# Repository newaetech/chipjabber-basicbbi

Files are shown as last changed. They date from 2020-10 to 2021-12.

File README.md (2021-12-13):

# ChipJabber-BasicBBI

What the heck is Body Biasing Injection? This is a method of injecting faults into the backside of an IC, which results in an injection somewhere between EMFI & Laser-FI. This work has been presented since 2012, yet there has been less follow on work compared to topics such as EMFI & Laser FI. ChipJabber-BasicBBI tries to help with that by making available both the injection tool & target for all!

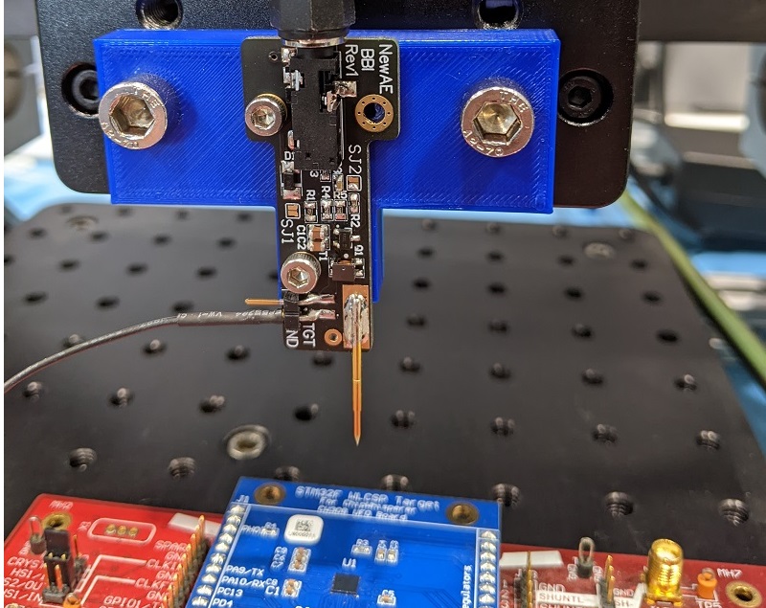
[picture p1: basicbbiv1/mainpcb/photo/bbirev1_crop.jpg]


You can see the following papers for the origins of this:

* Philippe Maurine. **Techniques for EM Fault Injection: Equipments and Experimental Results**. FDTC 2012: Workshop on Fault Diagnosis and Tolerance in Cryptography. 9 Sept. 2012. [PDF Available](https://hal-lirmm.ccsd.cnrs.fr/lirmm-00761778/document).

* Philippe Maurine, Karim Tobich, Thomas Ordas, Pierre Yvan Liardet. **Yet Another Fault Injection Technique: by Forward Body Biasing Injection**. YACC’2012: Yet Another Conference on Cryptography, Sep 2012, Porquerolles Island, France.  [PDF Available](https://hal-lirmm.ccsd.cnrs.fr/lirmm-00762035/document).

* Karim Tobich, Philippe Maurine, Pierre Yvan Liardet, Mathieu Lisart, Thomas Ordas. **Voltage Spikes on the Substrate to Obtain Timing Faults**. 2013 Euromicro Conference on Digital System Design, Los Alamitos, CA, 2013, pp. 483-486. [PDF Available](https://www.researchgate.net/profile/Philippe_Maurine/publication/262352179_Voltage_Spikes_on_the_Substrate_to_Obtain_Timing_Faults/links/54b805100cf2c27adc487b12/Vo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)

* Noemie Beringuier-Boher, Marc Lacruche, David El-Baze, Jean-Max Dutertre, Jean-Baptiste Rigaud, Philippe Maurine. **Body Biasing Injection Attacks in Practice**. In Proceedings of the Third Workshop on Cryptography and Security in Computing Systems (CS2 '16), 2016. [PDF Available](https://dl.acm.org/doi/pdf/10.1145/2858930.2858940)

## BBI Made Simple

BBI uses a simple idea - use a physical probe on the IC die *backside*. While it turns out that WLCSP devices expose the backside (or have some flimsy film over it you can remove easily), allowing you to perform BBI without becoming [John McMaster](https://twitter.com/johndmcmaster).

The idea of this repo is to perform BBI using a simple probe, which uses a transformer to generate the required pulses. This looks something like this:

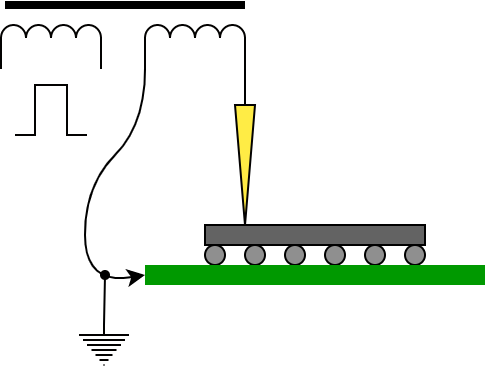
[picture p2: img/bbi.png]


## CARDIS 2020 Paper

This work was presented at CARDIS 2020, see an extended version of the paper in the [CARDIS](cardis2020/ChipJabber_BBI.pdf) directory of this repository. If you use these results (or this design), please reference:

```
O'Flynn, Colin. (2021) Low-Cost Body Biasing Injection (BBI) Attacks on WLCSP Devices.
In: Liardet PY., Mentens N. (eds) Smart Card Research and Advanced Applications. CARDIS 2020.
Lecture Notes in Computer Science, vol 12609. Springer, Cham. https://doi.org/10.1007/978-3-030-68487-7_11
```

You can pull the citation from the [SpringerLink page](https://link.springer.com/chapter/10.1007/978-3-030-68487-7_11#citeas) as well.

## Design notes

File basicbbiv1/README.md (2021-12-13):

# BasicBBI-Rev1

The BasicBBI Rev1 allows assembly with off-the-shelf parts, while adding some critical features such as mounting holes and protection from easily destroying the probe. The current test board ('PCB Rev A') looks like this:

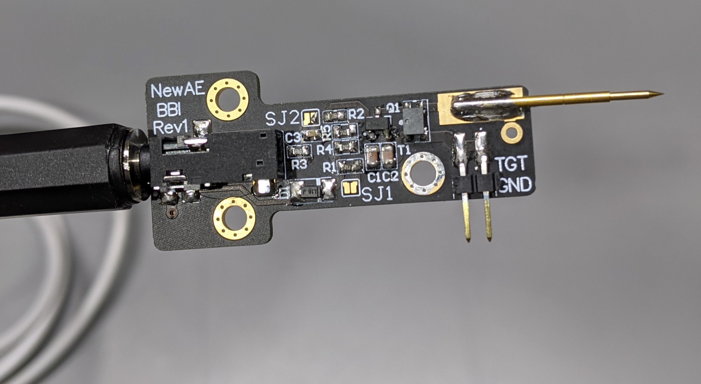
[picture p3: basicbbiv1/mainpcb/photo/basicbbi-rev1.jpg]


It requires a 3.3V logic-level waveform from the ChipWhisperer board (or any other signal source).

## Usage

See the CARDIS 2020 paper for general information on the design & usage of this device. You'll need a 3.5mm, 4-conductor "tip ring ring sleeve" cable. You can use any generic off-the-shelf cable, or for example you can even buy from Digi-Key cables such as 839-1600-ND which saves you needing to cut a cable in half!

```
 +------------ Pulse input (logic level drive, AC-coupled)
 |  +--------- Optional pull-up or termination.
 |  |
<[] [] [] []|======
       |  |
       |  +--- GND
       +------ Voltage In (range, 0 to 30V. Use small current limit such as 50mA)
```

To prevent you from blowing up the transformer T1 or MOSFET Q1, the input pulse drive is AC-coupled. You can remove this coupling by shorting `J2`.

The "optional pull-up" was originally designed to allow driving the BBI probe directly from a ChipWhisperer "glitch" output - this doesn't work well in practice, as you need a very long "glitch width" in order to get a positive
spike on the MOSFET gate (and not the negative spike you'll see with narrow pulses). Mostly you can leave the "optional pull up" wire disconnected without issue.

### Connections

1. Connect a pulse generator to the `Pulse Input`. In the COSADE BBI work, the ChipWhisperer-Lite is used. You can use either the HS2 output, or if you need to use HS2 for clock output, the header JP8 has the signals 
   routed to the "glitch_lp" and "glitch_hp" MOSFETs. The center pin has the "glitch_lp" mosfet drive signal, and can be routed to the `Pulse input` of the BBI probe.

2. Connect a 0V to 30V power source that has a 100~mA current limit to the probe. A 75-ohm resistor tries to limit current, but at 30V this means up to 400mA will flow, so it is preferred if you have a current limited supply.

3. Place the bbi probe over your WLCSP device. If you aren't sure if the package exposes the die backside, use a DMM to check for a 20K-400K resistance between the die backside and VCC or GND.

4. Connect the output of the transformer "ground" pin (the not-needle-side) to target pcb gnd.

5. Hit that fault inject button!

If you want a starting point, see the Jupyter notebook for the CARDIS paper.

## Parts

The following are the 'specific' parts used in the design (format is `QTY, PART NUMBER, DESIGNATOR`).

```
1,B260A,D1
1,AO3422,Q1
1,ATB322524,T1
1,TSM-102-01-L-SH,J1
1,P25-0123,PROBE
```

If you need to sub `D1` or `Q1`:

* D1 is for reverse polarity protection so can be skipped. If you can't find that part use the following:
	* DO-214AC (SMA) package (SOD123 packages fit - a SOD123 package diode is in the photo)
	* Schottky
	* 500mA or higher current rating
	* 40V or higher voltage rating
* Q1 is a logic-level MOSFET in SOT23 package. If you need a replacement use the following criteria:
	* N-Channel
	* Check pinout matches expected
	* Logic level drive (spec of something like 2.5V 'Max Rds On', 4.5V 'Min Rds On')
	* 1.8A or higher (only for pulse current reasons - can get away with smaller one)
	* 45V or higher Drain to Source Voltage (Vdss)

Currently (Dec 2021) there is limited stock of suitable MOSFETs, if you can't find one see Issue #1. 
 
`J1` can be sub'd with any header that you can solder, or even just wire.

`PROBE` is a sharp pogo pin. The Harwin `P25-0123` is a good low-cost option, you can get fancier (smaller point) probes too.

The other parts are very generic, I didn't have part numbers for them:

```
1, 100n 0603 [Generic]
2, 4.7uF 0805 50V or 63V [Generic]
1, 10K 0805 5% or 1% [Generic]
2, 1K 0603 5% or 1% [Generic]
```

## Schematic

A PDF of the schematic is in the repo, here is a image for convenience:

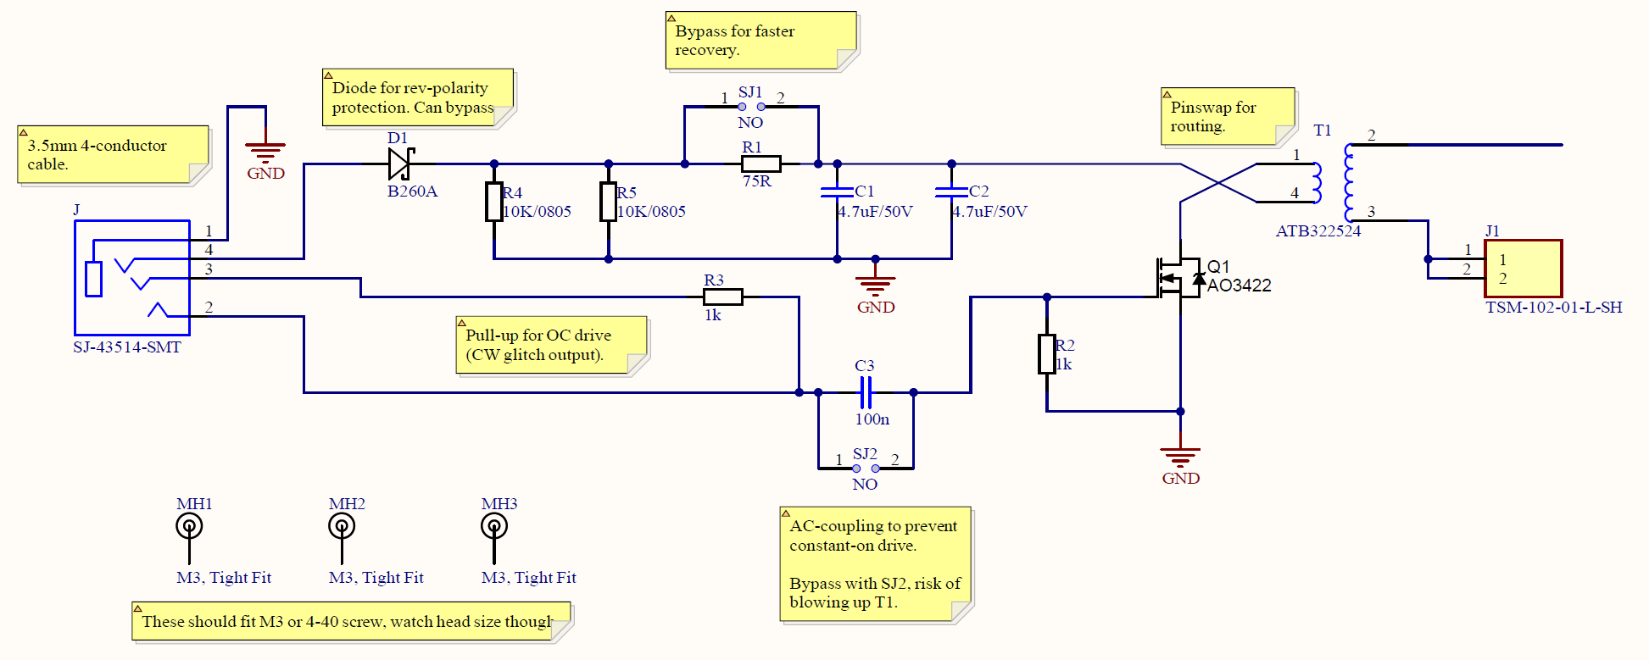
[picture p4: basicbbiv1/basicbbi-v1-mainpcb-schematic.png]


## PCB

PCB gerbers are in the repo.

One version of the gerbers has been generated with the Bantam Mill output standard. The vias around the mounting holes have also been removed in this version (since they would probably damage your bit and do nothing with a milled PCB).

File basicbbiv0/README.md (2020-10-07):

# ChipJabber-BasicBBI Rev0

This revision of the BBI probe matches the one in Colin's CARDIS 2020 paper. It was originally designed to be made on a Bantam PCB mill, so is extremely bare-bones.

## Construction Instructions

### PCB Details

The PCB was built with parts on hand, so it is very bare-bones. You might want to see Rev1 edition for a better design.

The following shows the schematic:

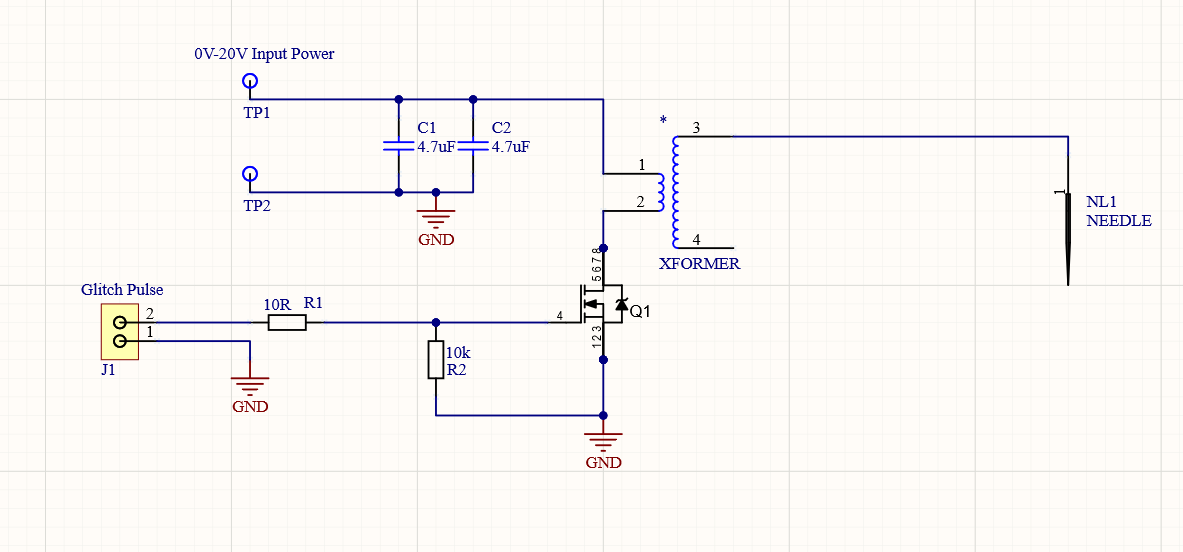
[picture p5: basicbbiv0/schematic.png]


And the base PCB:

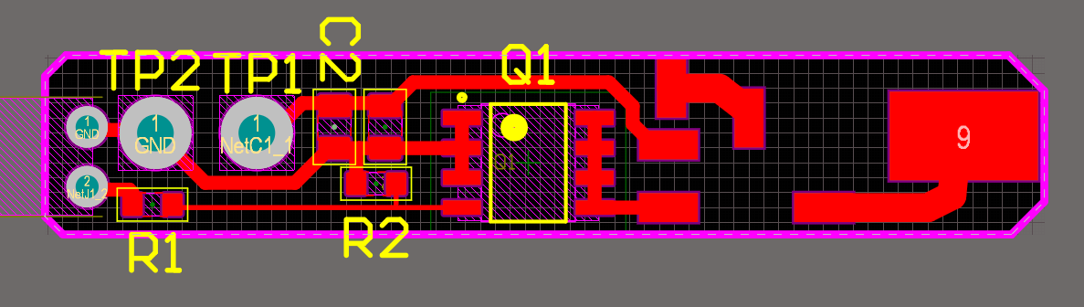
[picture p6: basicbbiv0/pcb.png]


Gerber files are in the relevant directory, they should be loadable in the Bantam PCB milling software. If you are going to the effort of ordering PCBs, suggest to use the V1 edition instead which more effort was put into.

### Custom Coil Winding

The "heart" of BasicBBI is a custom wound coil. This coil is surprisingly uncritical how you wind it, but you've got to do it. The suggested coil is based on these parts:

* Fair-Rite rod [3061990871](https://www.digikey.ca/en/products/detail/fair-rite-products-corp/3061990871/8599472)
* 26 AWG, and 30 AWG magnetic wire, available in [Sparkfun PRT-11363](https://www.digikey.ca/en/products/detail/sparkfun-electronics/PRT-11363/5230957)

Optionally, you may find some Super-Glue + Accelerator/Activator convenient to freeze your windings in place. 

To wind the coil:

1. Wind 6 turns of 26 AWG magnet wire, this is the primary.
2. Use some glue (the super-glue + accelerator is easiest here) to hold the winding in place.
3. Wind 60 turns of the 30 AWG magnet wire on-top. You'll have to go back and forth several times. It can be fairly messy and still seems to work fine.

Leave lots of spare wire, as you can tin the wires once you see how it fits onto the PCB. See details below.

### PCB Assembly

In addition to the coil, you will need a pogo pin. Harwin P25-0123 is available on Digikey & Mouser, otherwise you can find similar ones on various cheaper sites if you wish.

The assembled probe could look something like this:

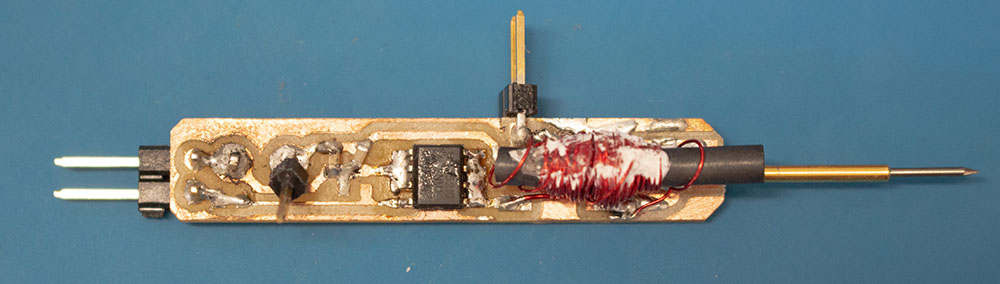
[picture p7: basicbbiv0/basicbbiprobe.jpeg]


## Usage Instructions

To use this probe:

1. Connect a pulse generator to the MOSFET gate. In the COSADE BBI work, the ChipWhisperer-Lite is used. The signal routed to the on-board mosfet is tapped off at JP8, the center pin as the "glitch_lp" mosfet drive signal.

2. Connect a power source that has a 100~mA current limit to the probe. If you don't have a current limited supply, use a ~100 ohm resistor inline. The probe discharges from the capacitors on-board anyway. **WARNING: Using a non-current-limited supply it becomes likely you accidentally turn on the MOSFET for too long, which will have a direct short across the supply rails.**

3. Place the bbi probe over your WLCSP device. If you aren't sure if the package exposes the die backside, use a DMM to check for a 20K-400K resistance between the die backside and VCC or GND.

4. Connect the output of the transformer "ground" pin (the not-needle-side) to target pcb gnd.

5. Hit that fault inject button!

If you want a starting point, see the Jupyter notebook for the CARDIS paper.

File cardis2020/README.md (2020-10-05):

# Jupyter Notebooks

This repo contains the notebooks used for data capture, along with generating figures used in Colin's
paper in CARDIS2020. You can see an example of the Jupyter notebook here:

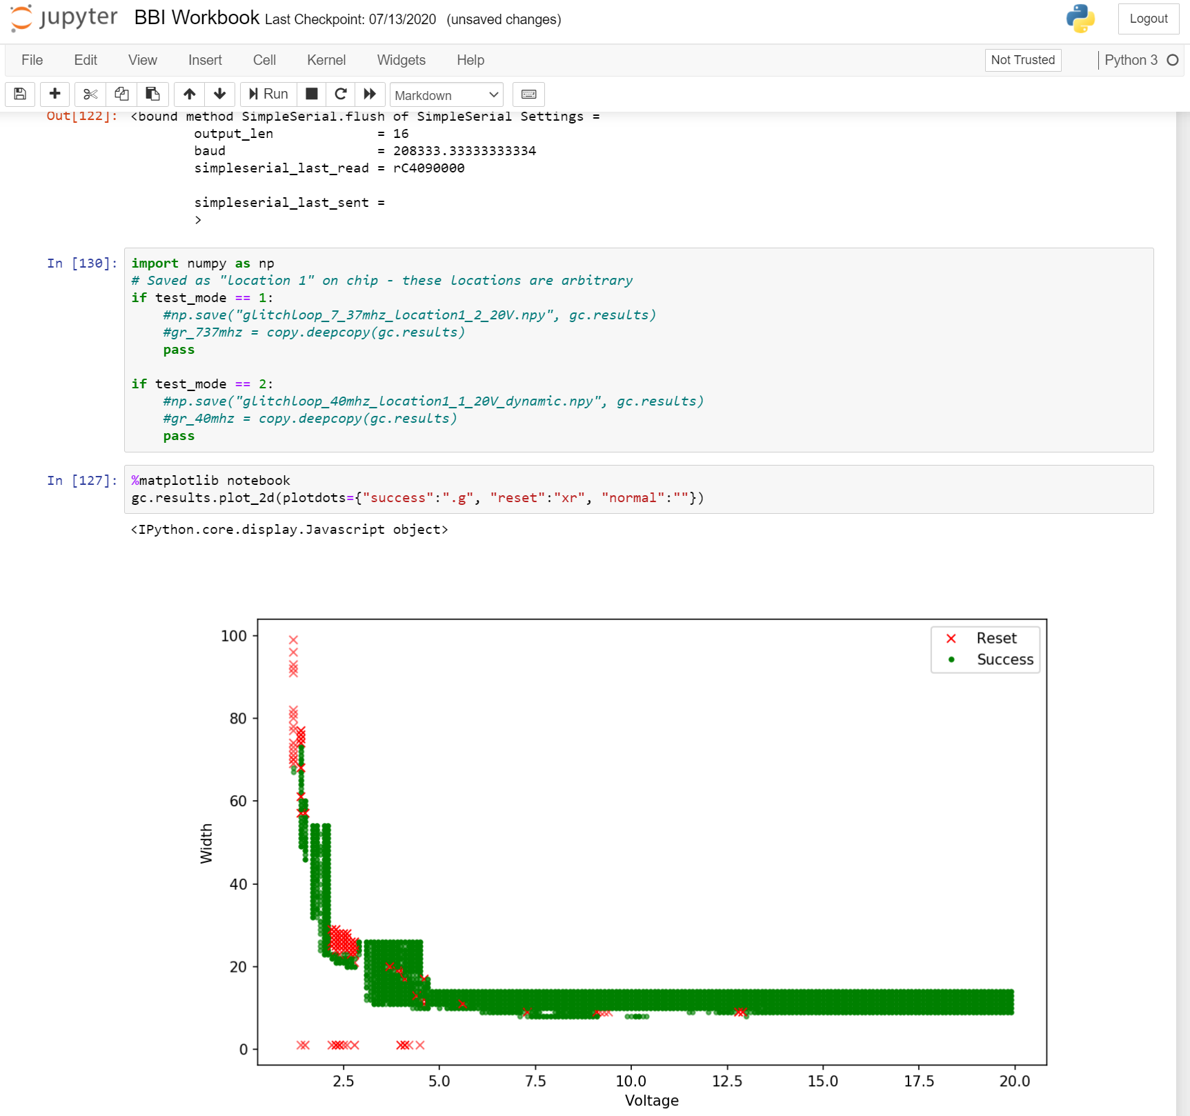
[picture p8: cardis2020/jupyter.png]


## XY Scanner Results

Using a ChipShover controller, we scan part of the WLCSP package. The area scanned is shown below:

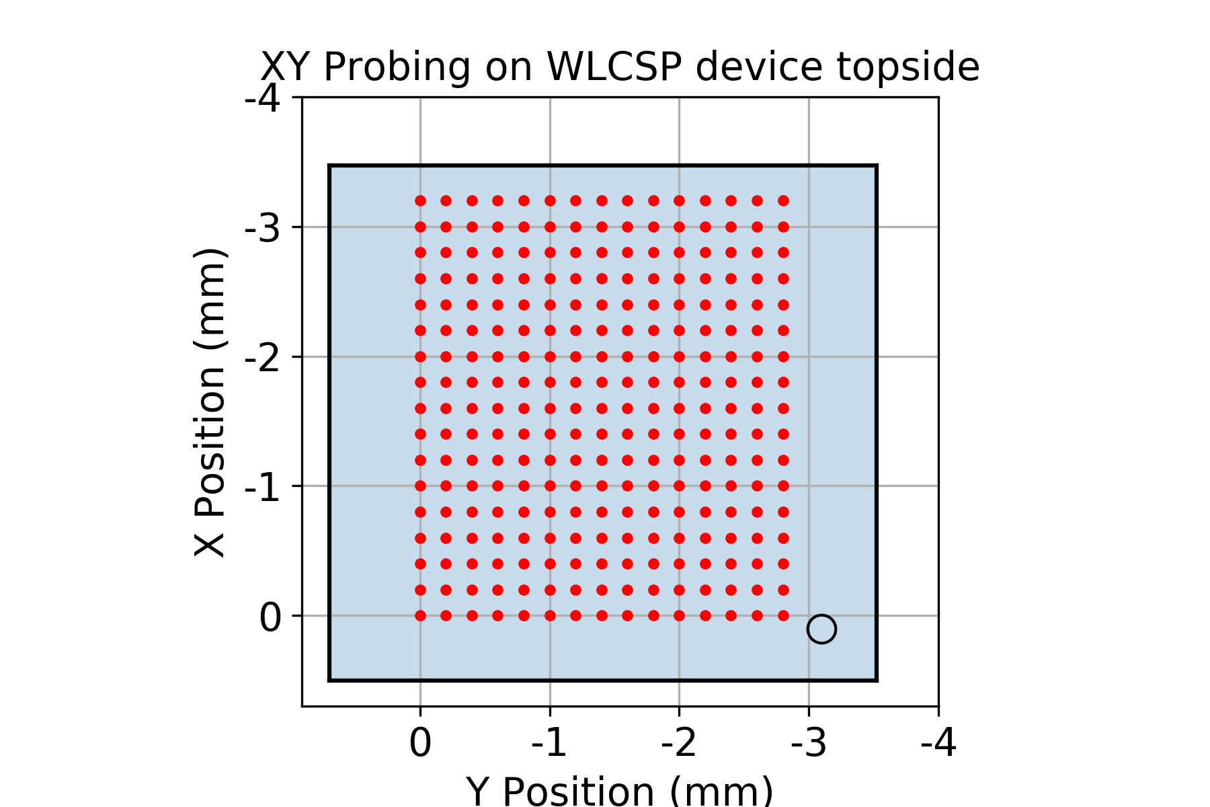
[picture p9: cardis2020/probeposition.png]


We can see the number of successes and rests at locations:

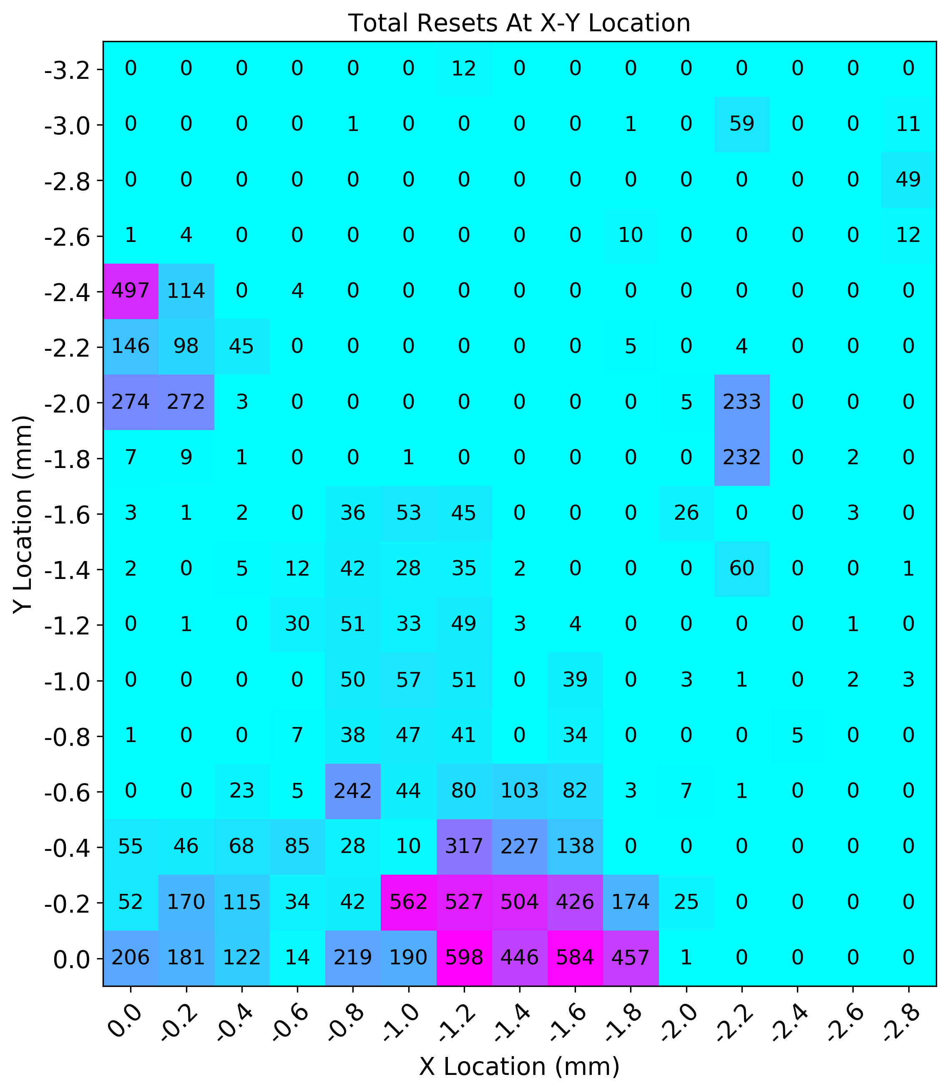
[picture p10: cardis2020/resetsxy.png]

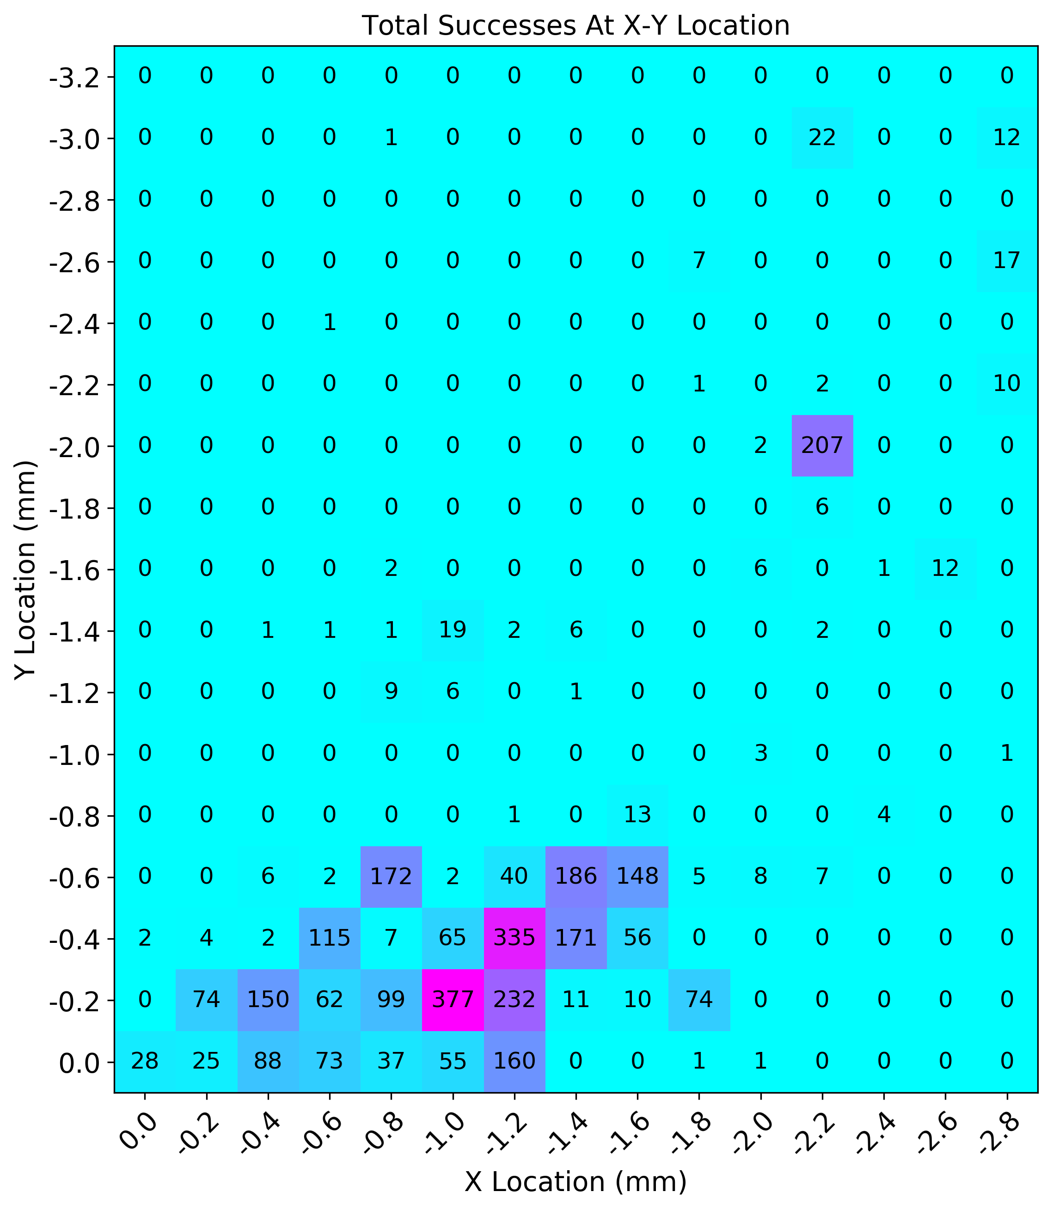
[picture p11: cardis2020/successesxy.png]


We can also see the voltage setting required to get at least one successful glitch:

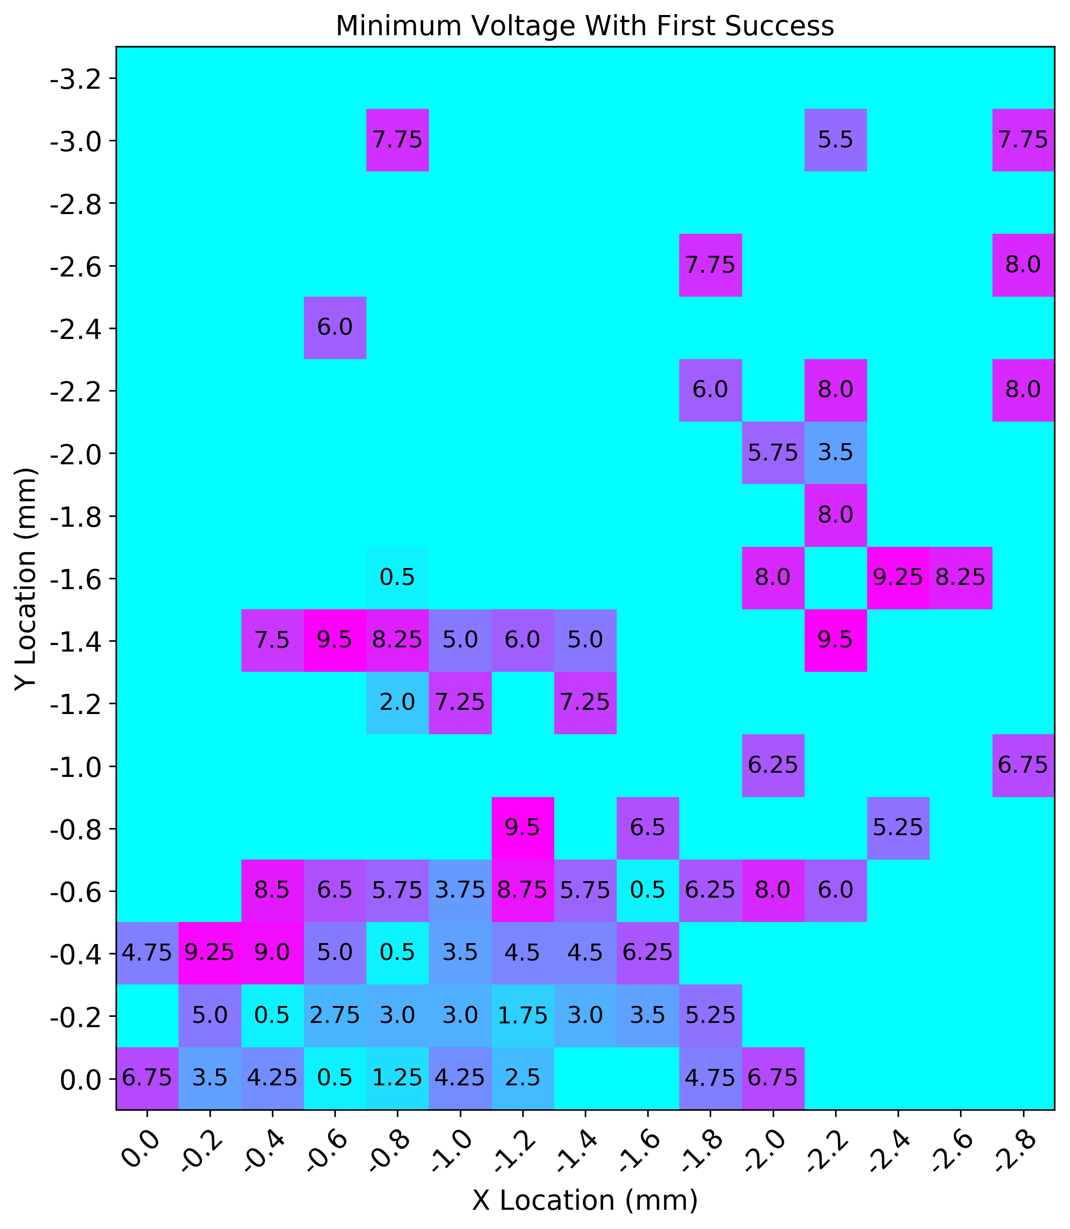
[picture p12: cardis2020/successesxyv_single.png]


Or at least 10 successful glitches:

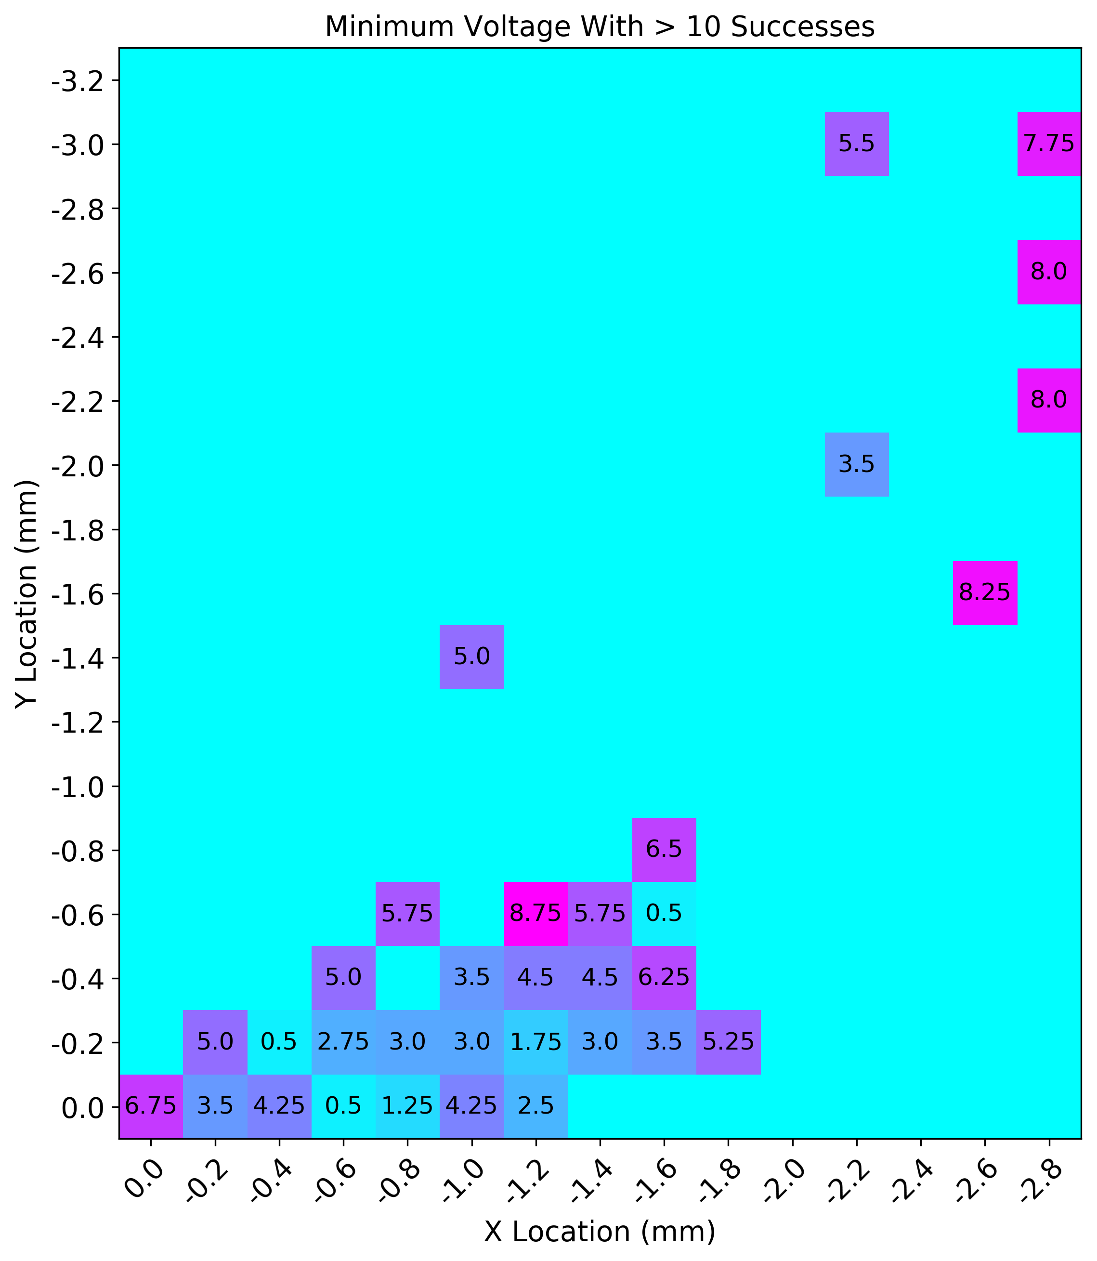
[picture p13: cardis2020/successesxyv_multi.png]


A notebook allows you to recreate these figures, but also contain the raw data captures. You can use this to plot other information.

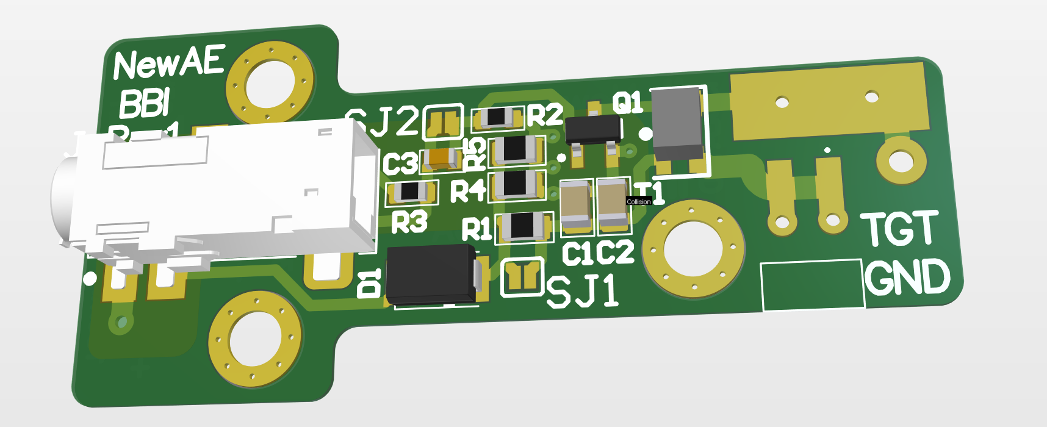
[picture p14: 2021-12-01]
basicbbiv1/mainpcb/photo/pcb_render.png

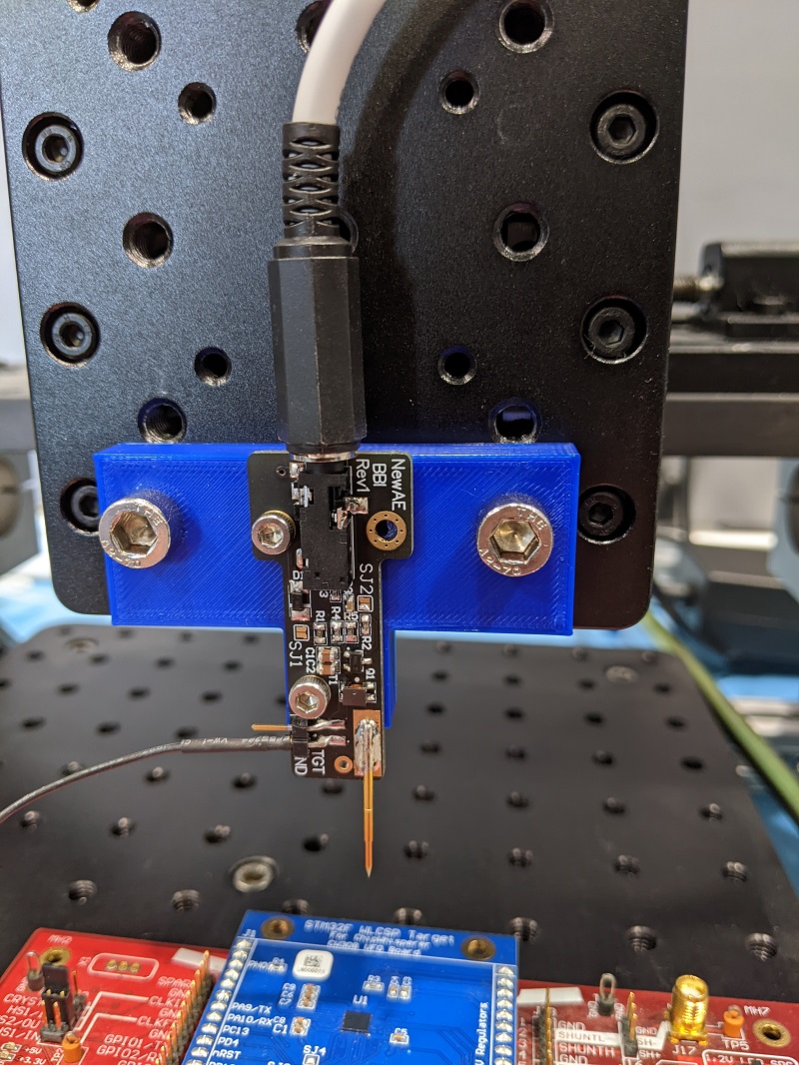
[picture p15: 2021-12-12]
basicbbiv1/mainpcb/photo/bbirev1.jpg

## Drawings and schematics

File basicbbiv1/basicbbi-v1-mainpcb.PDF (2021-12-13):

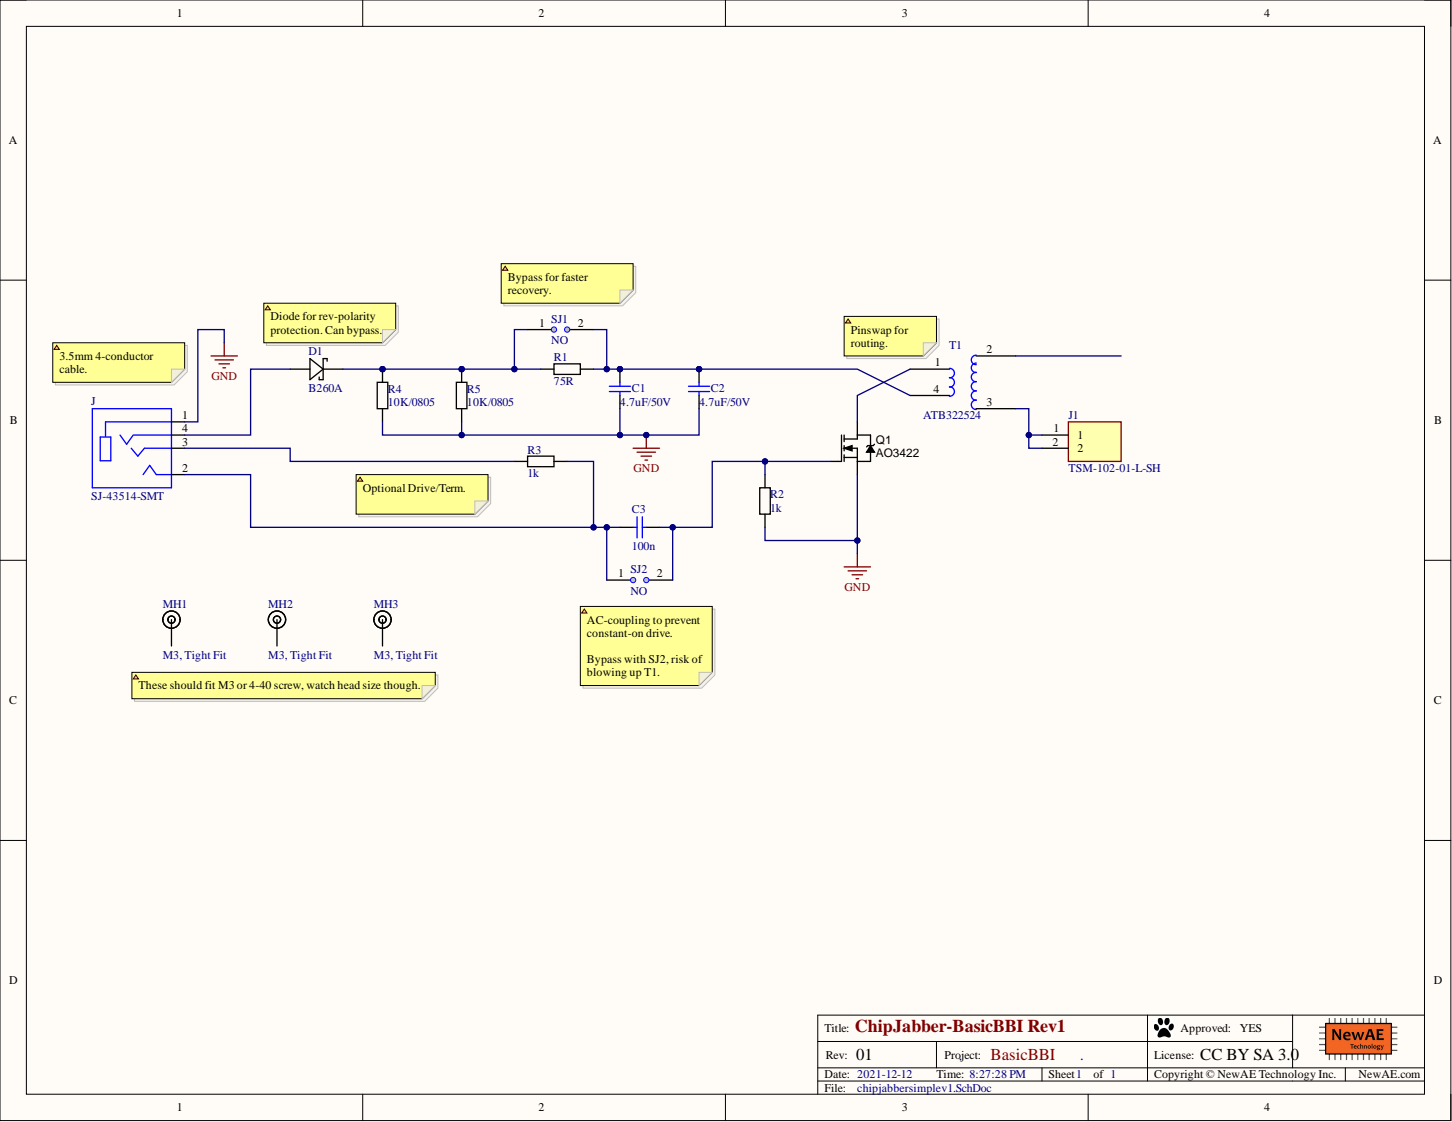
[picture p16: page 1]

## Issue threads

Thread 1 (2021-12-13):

MOSFET Part Numbers

colinoflynn, 2021-12-13:
This issue is used to track replacement part numbers for the MOSFET. AO3422 used in the design is out of stock (as of Dec 2021).

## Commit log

2020-10-07 Add altium files, PCB, schematic
    [bbilibs.PcbLib, bbilibs.SchLib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]
2020-10-07 Expand assembly readme
2020-10-07 Add photo of bbi probe
2021-12-01 Add BasicBBIRev1
    [bbi-simple-rev1.GBL, bbi-simple-rev1.GBO, bbi-simple-rev1.GBP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]
2021-12-01 Add milled gerbers, minor updates on docs
    [chipjabber-bbi-simplev1.PrjPcb, chipjabbersimplev1.SchDoc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]
2021-12-12 Note that PCB works
2021-12-13 Update sch with removal of pull-up
    [chipjabber-bbi-simplev1.PrjPcb, chipjabbersimplev1.SchDoc]
2021-12-13 Add more usage, link to mosfet PN issue
